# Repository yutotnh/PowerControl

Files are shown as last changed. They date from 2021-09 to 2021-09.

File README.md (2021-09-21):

# PowerControl

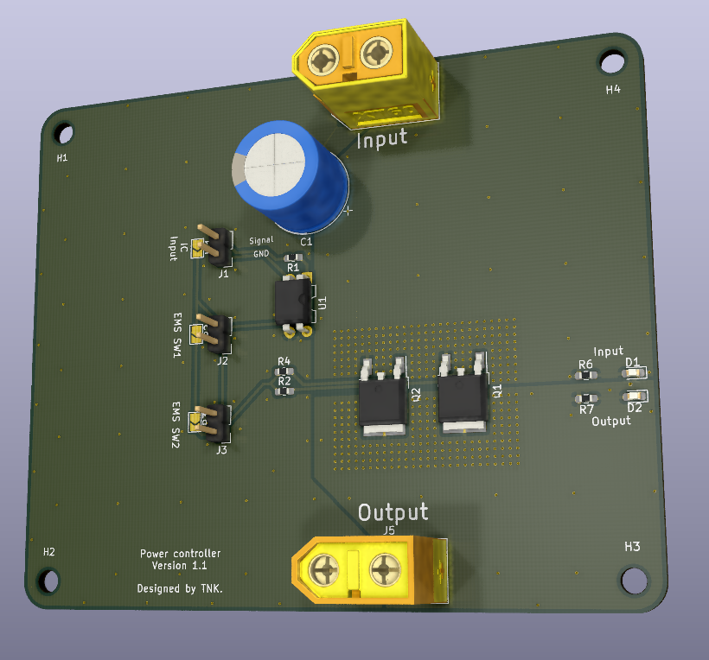
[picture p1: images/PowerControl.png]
PowerControl


## 機能の説明
本基板は、電源の制御回路です。

最大3つのスイッチを用いて電源のON/OFF制御ができます。

常時許容電流は70A程度です(銅箔厚:1ozの場合。使用する環境やMOSFETの性能によって低下します)。

各スイッチはAND構成で接続しているため、全てのスイッチがONになったときのみ電流が流れます。

## 使い方

### スイッチの構成

本基板には3つのスイッチを接続するコネクタが用意されています。

スイッチの構成は以下です。

| リファレンス | 基板上の表記 | 対象スイッチ | ON | 対応ソルダジャンパ |
| --- | --- | --- | --- | --- |
| J1 | IC Input | マイコン等の入力  | フォトカプラがON | JP1 |
| J2 | EMS SW2 | 非常停止スイッチ2 | スイッチがON | JP2 |
| J3 | EMS SW1 | 非常停止スイッチ1 | スイッチがON | JP3 |

動作チェック時など、一部のスイッチを接続しない場合は、接続しないスイッチの真下のソルダジャンパ(JP1~JP3)をショートすることで接続を省略することができます。

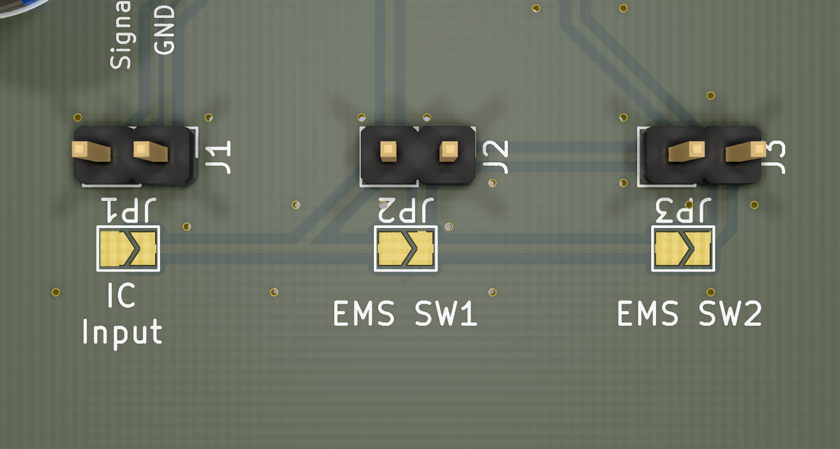
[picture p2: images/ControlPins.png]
ControlPins


### スイッチの接続

#### IC Input

信号を絶縁するため、フォトカプラを通して電源を制御します。

Signal側のピンにマイコンの5Vや3.3V等の出力を入力、GND側にマイコンが使用しているGNDを入力してください。

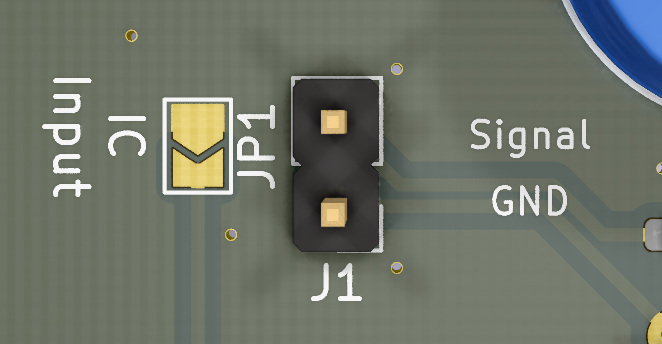
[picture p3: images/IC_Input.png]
IC Input


#### EMS SW

非常停止スイッチ接続用のため、極性などは気にする必要はありません。

## 確認用LED

入力側と出力側の両方のON/OFF確認用LEDを用意しています。

LEDが点灯している場合ONの状態です。

LEDを実装する場合は、入力側と出力側で異なる色のLEDにすると状態を視認しやすくなると思います。

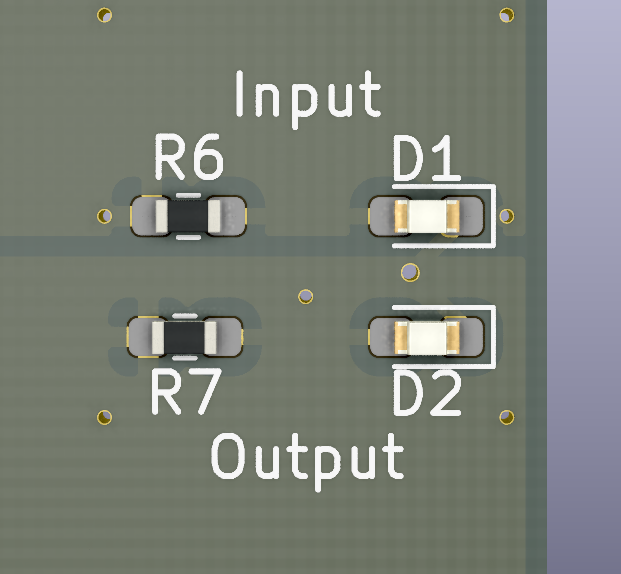
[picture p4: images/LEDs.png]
LEDs


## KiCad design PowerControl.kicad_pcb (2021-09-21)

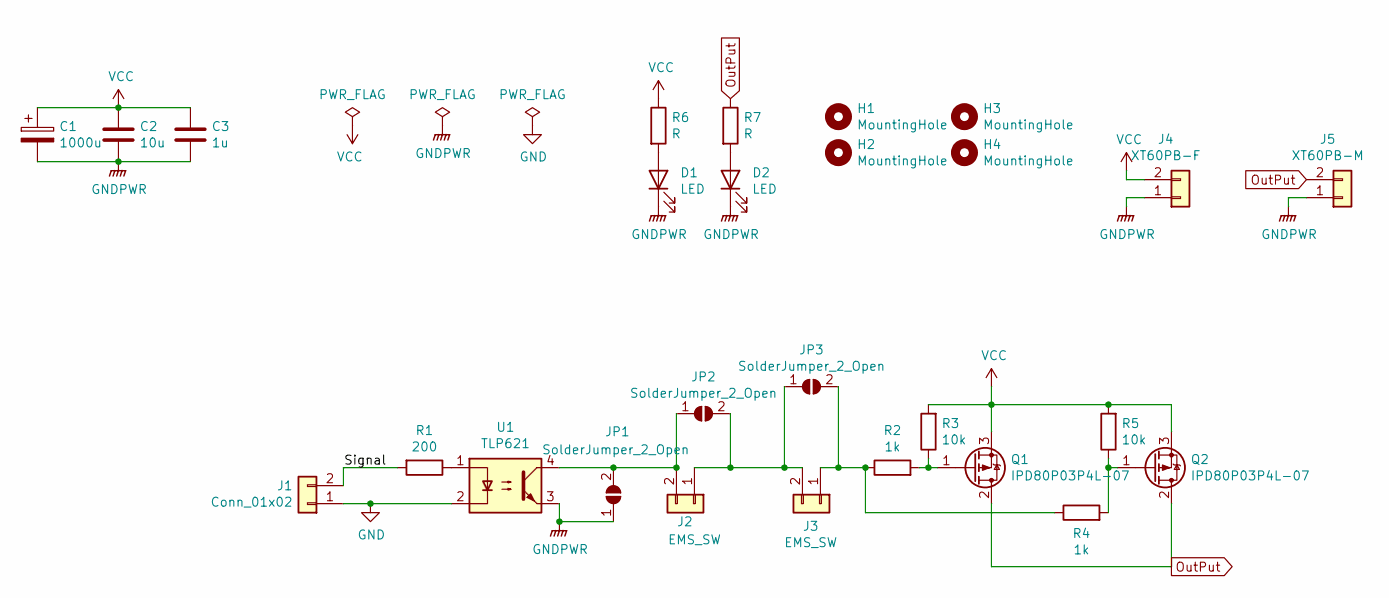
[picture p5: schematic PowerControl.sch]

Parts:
C1: 1000u; CP_Radial_D12.5mm_P5.00mm
C2: 10u; C_0805_2012Metric_Pad1.15x1.40mm_HandSolder
C3: 1u; C_0805_2012Metric_Pad1.15x1.40mm_HandSolder
D1, D2: LED; LED_0603_1608Metric_Pad1.05x0.95mm_HandSolder
H1, H2, H3, H4: MountingHole; MountingHole_3.2mm_M3
J1: Conn_01x02; PinHeader_1x02_P2.54mm_Vertical
J2, J3: EMS_SW; PinHeader_1x02_P2.54mm_Vertical
J4: XT60PB-F; AMASS_XT60-F_1x02_P7.20mm_Vertical
J5: XT60PB-M; AMASS_XT60-M_1x02_P7.20mm_Vertical
JP1, JP2, JP3: SolderJumper_2_Open; SolderJumper-2_P1.3mm_Open_TrianglePad1.0x1.5mm
Q1, Q2: IPD80P03P4L-07; TO-252-2
R1: 200; R_0603_1608Metric_Pad1.05x0.95mm_HandSolder
R2, R4: 1k; R_0603_1608Metric_Pad1.05x0.95mm_HandSolder
R3, R5: 10k; R_0603_1608Metric_Pad1.05x0.95mm_HandSolder
R6, R7: R; R_0603_1608Metric_Pad0.98x0.95mm_HandSolder
U1: TLP621; DIP-4_W7.62mm

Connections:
/Signal: J1.2, R1.2
GND: J1.1, U1.2
GNDPWR: C1.2, C2.2, C3.2, D1.1 (K), D2.1 (K), J4.1, J5.1, JP1.1 (A), U1.3
unnamed: D1.2 (A), R6.2
unnamed: D2.2 (A), R7.2
unnamed: J2.1, J3.2, JP2.2 (B), JP3.1 (A)
unnamed: J2.2, JP1.2 (B), JP2.1 (A), U1.4
unnamed: J3.1, JP3.2 (B), R2.1, R4.1
unnamed: Q1.1 (G), R2.2, R3.1
unnamed: Q2.1 (G), R4.2, R5.1
unnamed: R1.1, U1.1
OutPut: J5.2, Q1.2 (D), Q2.2 (D), R7.1
VCC: C1.1, C2.1, C3.1, J4.2, Q1.3 (S), Q2.3 (S), R3.2, R5.2, R6.1

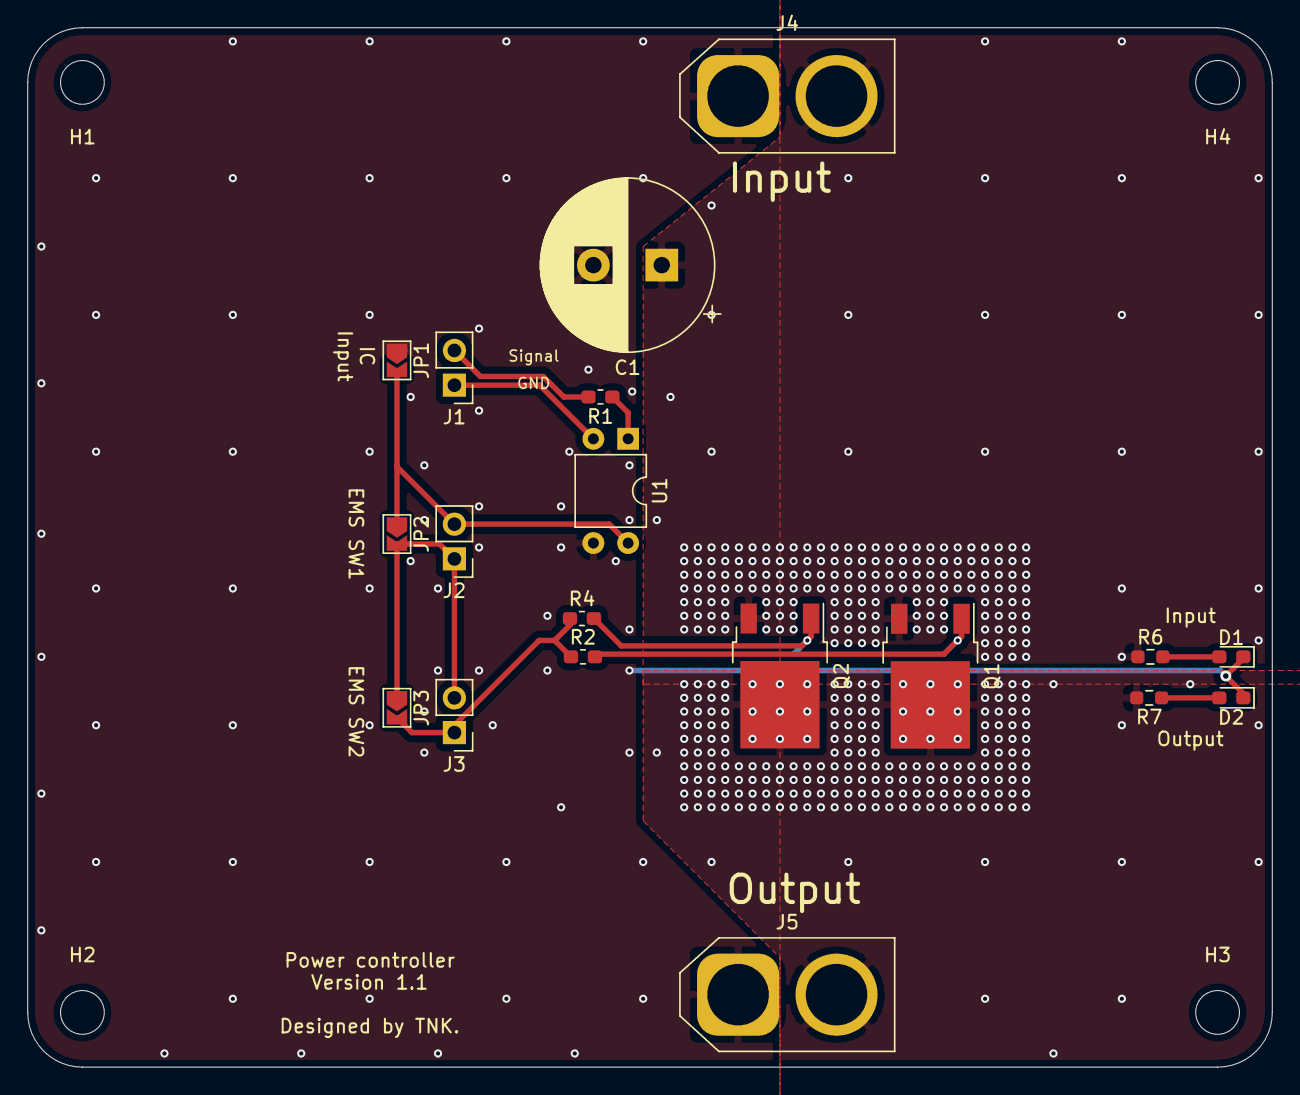
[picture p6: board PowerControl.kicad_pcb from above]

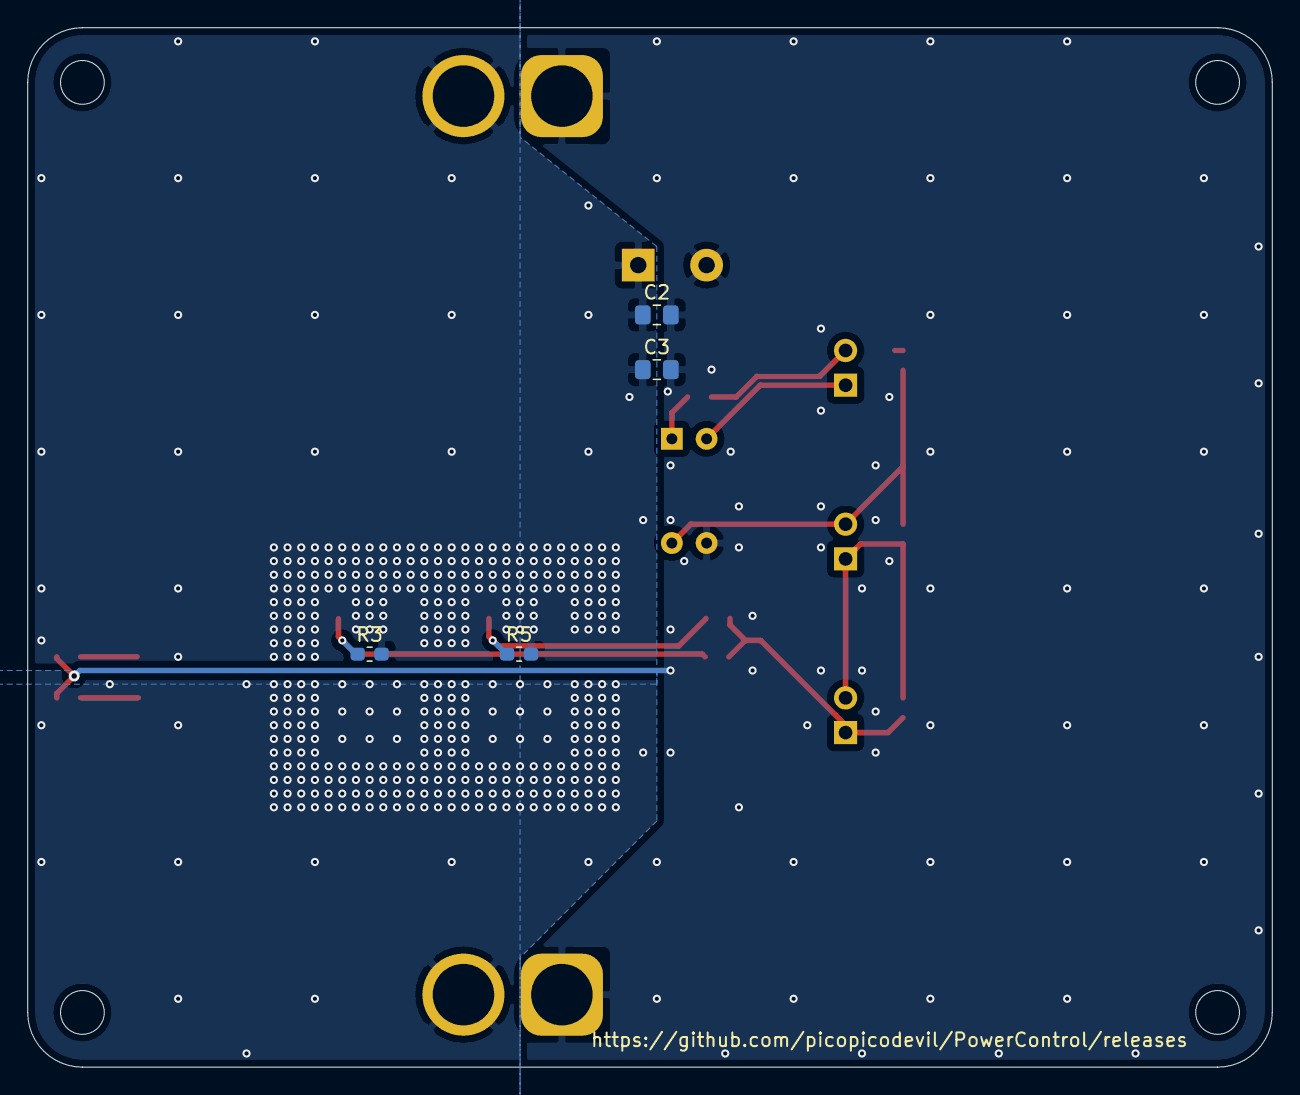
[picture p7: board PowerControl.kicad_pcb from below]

Board: 2 copper layers, 91.0 x 76.0 mm, 27 parts (4 on the bottom side), 13 nets.

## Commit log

2020-06-22 start project
    プロジェクトおよびファイルを作成
    [PowerControl.kicad_pcb, PowerControl.sch]
2020-06-23 change
    Eeschemaでの主な設計
    [PowerControl.kicad_pcb]
2020-07-04 Add board
    基本的な設計が終了
    [PowerControl.kicad_pcb, PowerControl.sch]
2020-07-04 change Pch MOSFET name
    Pch MOSFETの名称をIPD80P03P4L-07に変更
    [PowerControl.kicad_pcb, PowerControl.sch]
2021-09-16 Update: .gitignoreにバックアップファイルを追加
2021-09-16 Remove: 不必要なファイルの削除
2021-09-16 Update: 配線幅などの変更
    [PowerControl.kicad_pcb]
2021-09-16 Fix: Pch MOSFETのゲートの印加電圧を修正(12V→GND)
    [PowerControl.sch]
2021-09-16 Update: ソルダージャンパの配置を変更
    [PowerControl.sch]
2021-09-16 Update: kicad_pcbに修正を変更
    [PowerControl.kicad_pcb]
2021-09-16 Update: 配線の変更
    [PowerControl.kicad_pcb]
2021-09-16 Update: シルクの修正
    [PowerControl.kicad_pcb]
2021-09-16 Update: 導通確認用のLEDを配置
    [PowerControl.kicad_pcb, PowerControl.sch]
2021-09-18 Update: 常時許容電流の補足文を追加
2021-09-18 Update: 塗りつぶしの再実行
    [PowerControl.kicad_pcb]
2021-09-21 Update: ガーバーファイルを出力
    [PowerControl.kicad_pcb]
